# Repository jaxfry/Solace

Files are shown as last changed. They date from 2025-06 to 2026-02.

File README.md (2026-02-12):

<div align="center">

# Solace

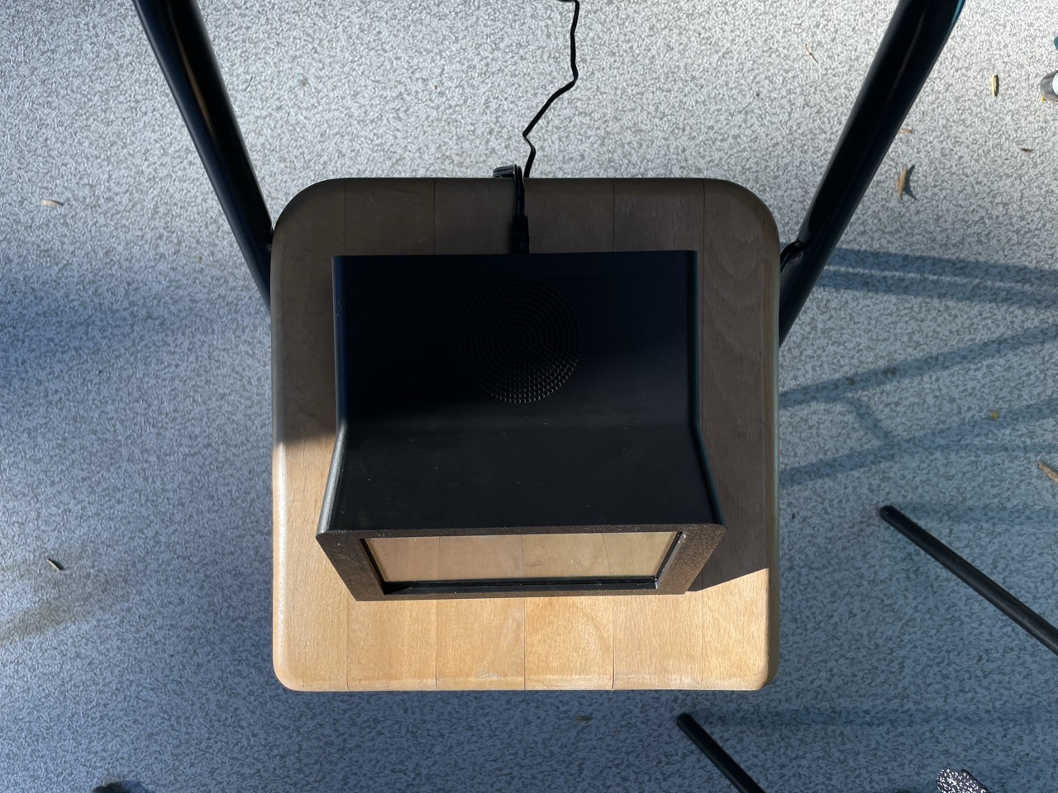
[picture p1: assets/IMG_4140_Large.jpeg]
Solace Build


## Description

**What is Solace?**

Solace is a physical extension of [LifeLog](https://github.com/jaxfry/LifeLog) that collects real-world data, displays real-time insights and statistics, and includes a voice assistant that integrates with the LifeLog system.

---

## Why I Made This

I wanted to create a physical device to complement the LifeLog system, providing a way to display data right beside my bed. I also wanted to create a voice assistant to further interact and for voice journal logging, a valuable data source.

---

## Project Pictures

### 3D Model

3D Model

### Wiring Diagram

Wiring Diagram

Please note that I used a generic buck converter in the diagram, but in the actual device I use a specific one.

### Bill of Materials (BOM)
|Part Name |Quantity|Price (CAD)|Description |Link |
|---|---|---|---|---|
|PLS-P830985 |1 |$30.65 |Speaker |https://www.digikey.ca/en/products/detail/peerless-by-tymphany/PLS-P830985/6211132 |
|Raspberry Pi Touch Display V1 |1 |$85.95 |7-inch touchscreen display for Raspberry Pi |https://www.digikey.ca/en/products/detail/raspberry-pi/ASIN-B00X4WHP5E/6211133 |
|Raspberry Pi 4 2GB |1 |$80.16 |Mini computer |https://www.amazon.ca/Raspberry-Model-2019-Quad-Bluetooth/dp/B07TD42S27/ |
|DAOKAI TPA3118 Mono Amplifier Board |1 |$9.14 |Audio amplifier for Raspberry Pi |https://www.amazon.ca/gp/product/B07SGK3VFS/ |
|TR9CE5000CCP-N(R6B) |1 |$$30.66 |power supply |https://www.digikey.ca/en/products/detail/mean-well-usa-inc/GST60A12-P1J/7703712 |
|PJ-037AH |1 |$1.01 |Power Jack |https://www.digikey.ca/en/products/detail/same-sky-formerly-cui-devices/PJ-037AH/1644547 |
|USB Mini Mic |1 |$6.99 |USB microphone for audio input |https://www.amazon.ca/Mini-Microphone-Skype-Desktop-Laptop/dp/B076BC2Y3W/ |
|0297005.U |1 |$0.57 |A 5A fuse, so I don't burn my house down |https://www.digikey.ca/en/products/detail/littelfuse-inc/0297005-U/3427486 |
|OKR-T/6-W12-C |1 |$13.89 |Buck converter |https://www.digikey.ca/en/products/detail/murata-power-solutions-inc/OKR-T-6-W12-C/2199629 |
|Aux Cable 1Ft |1 |$6.99 |A 1ft aux cable to connect the amp to the Raspberry Pi |https://www.amazon.ca/Tan-QY-Auxiliary-Compatible-Headphones/dp/B08BNMJ3ND/ |
|3021451F5701(R) |1 |$7.11 |Power Cord |https://www.digikey.ca/en/products/detail/globtek-inc/3021451F5701-R/8597816 |
|MFR-25FRF52-2K7 |1 |$0.15 |RES 2.7K OHM 1% 1/4W AXIAL |https://www.digikey.ca/en/products/detail/yageo/MFR-25FRF52-2K7/9138955 |
|EEU-FC1E101S |1 |$0.55 |Capacitor 100uF 25V |https://www.digikey.ca/en/products/detail/panasonic-electronic-components/EEU-FC1E101S/266278 |
|EEU-FR1A101 |1 |$0.47 |Capacitor 100uF 10V |https://www.digikey.ca/en/products/detail/panasonic-electronic-components/EEU-FR1A101/2433507 |
|C315C104M5U5TA |2 |$0.41 |Capacitor 0.1uF 50V |https://www.digikey.ca/en/products/detail/kemet/C315C104M5U5TA/817927 |
|28A2025-0A2 |1 |$3.84 |FERRITE CORE 320 OHM HINGED |https://www.digikey.ca/en/products/detail/laird-signal-integrity-products/28A2025-0A2/242803 |
|2Pack USB 3.0 Male to Female Adapter 7.9inches (20cm)|1 |$7.90 |USB 3.0 extension cable |https://www.amazon.ca/Female-Extension-Cable-Male-Female/dp/B084WPG7QG/ |
|110991327 |1 |$1.54 |Heat sink for the Raspberry Pi 4 |https://www.digikey.ca/en/products/detail/seeed-technology-co-ltd/110991327/10451876 |
|0FHM0001ZXJ |1 |$12.74 |Fuse Holder |https://www.digikey.ca/en/products/detail/littelfuse-commercial-vehicle-products/0FHM0001ZXJ/2004060|
|M2.5 Standoff kit |1 |$9.67 |M2.5 Standoff kit for mounting the Raspberry Pi and other components|https://www.amazon.ca/XLX-Male-Female-Female-Female-Assortment-Stainless/dp/B07FMV5RMG/ |
|FIT0585 |1 |$4.55 |18 AWG Wire |https://www.digikey.ca/en/products/detail/dfrobot/FIT0585/9559254?gQT=1 |
|uxcell |1 |$6.75 |M4*12 screws for speaker |https://www.amazon.ca/gp/product/B0F1YR73PB/ |
|Total | |$328.94 | | |

### Final Product Pictures
Final Product

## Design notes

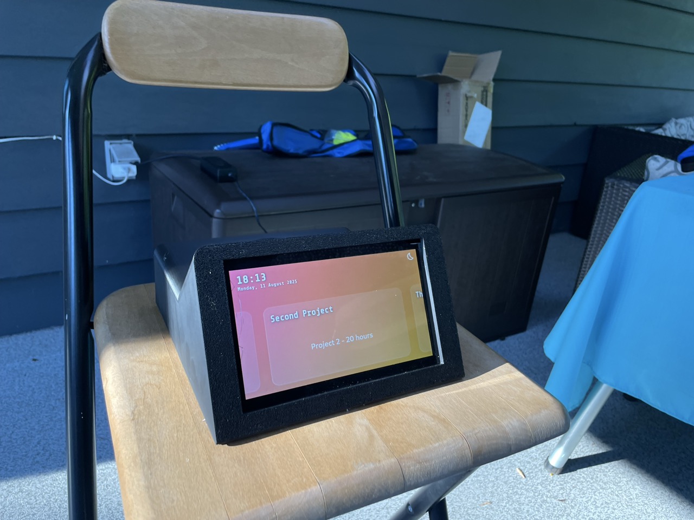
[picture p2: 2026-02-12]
assets/IMG_4137 Large.jpeg

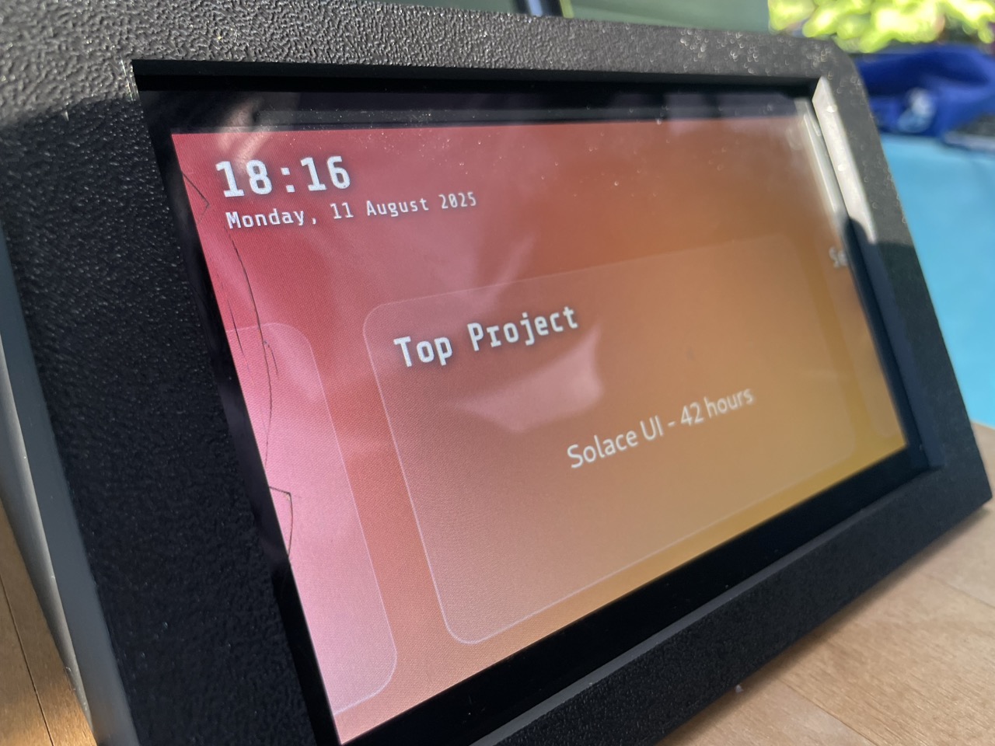
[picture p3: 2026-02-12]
assets/IMG_4144 Large.jpeg

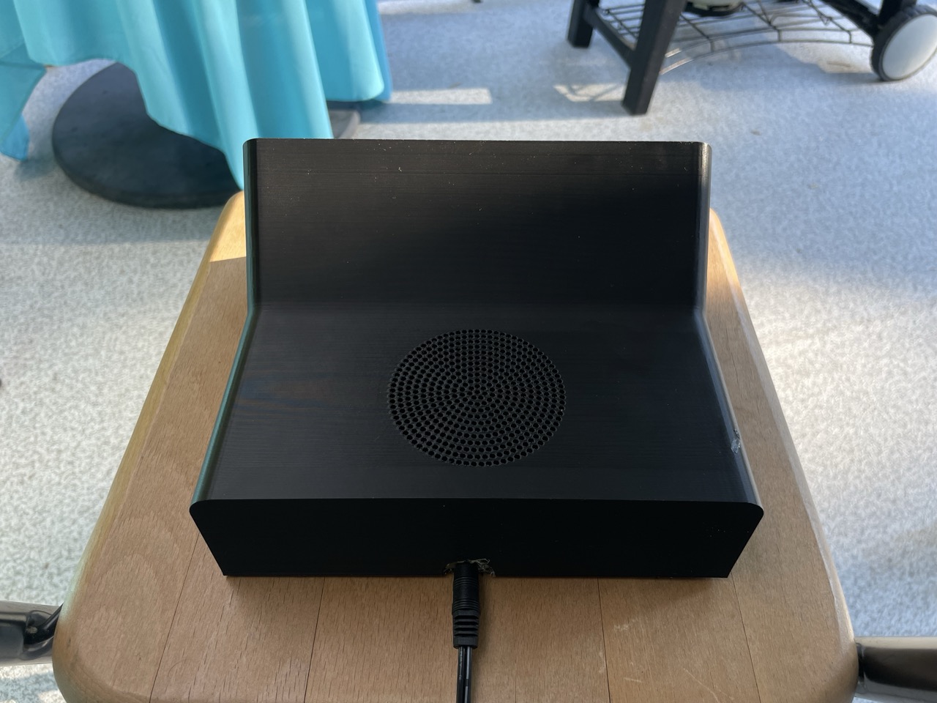
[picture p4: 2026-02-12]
assets/IMG_4146 Large.jpeg

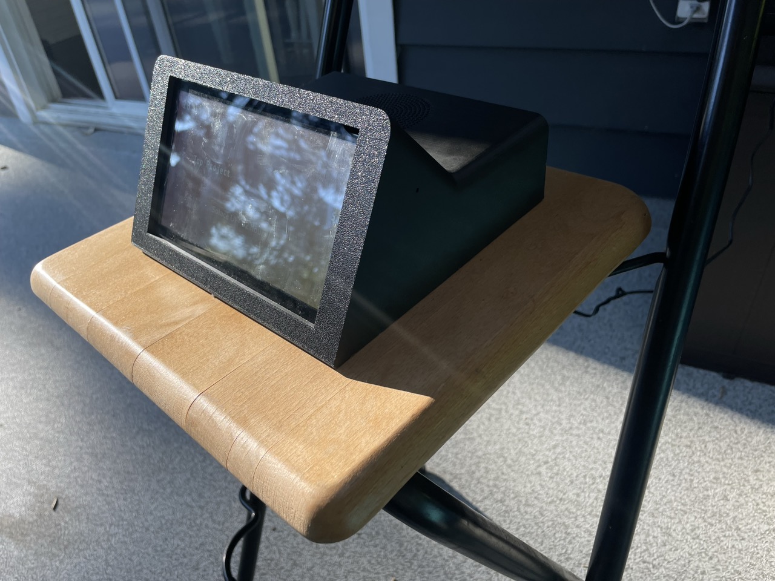
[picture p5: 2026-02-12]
assets/IMG_4142 Large.jpeg

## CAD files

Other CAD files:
Solace_CAD.f3d

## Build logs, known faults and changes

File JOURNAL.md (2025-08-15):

---
title: "Solace"
author: "Jaxon"
description: "A DIY Braun DN40-inspired alarm clock that’s also a LifeLog Satellite and smart speaker."
created_at: "2025-06-28"
total_design_time: "20 hours"
total_build_time: "~11 hours"
total_time: "~31 hours"
---
# 28 June 2025 - Project Kick-off (3 Hours)
- Drafted project goals and some technical details
- Flashed Raspberry Pi 3 for testing
- Sucsessfully got display to connect
- Got flutter set up and demo working
- Set up dev enviroment on macbook
- Started (re)Learning Flutter Basics
- Started thinking about the layout of the UI
# 29 June 2025 - Components Research (1 hour)
I was researching different types of displays, but ended up deciding upon a standard raspberry pi display after much concideration for a nice AMOLED screen, it's just too expensive. I'll make a BOM soon!
# 29 June 2025 - Design sketch (30 mins)
- Just sketched a design and wrote about Solace and LifeLog.
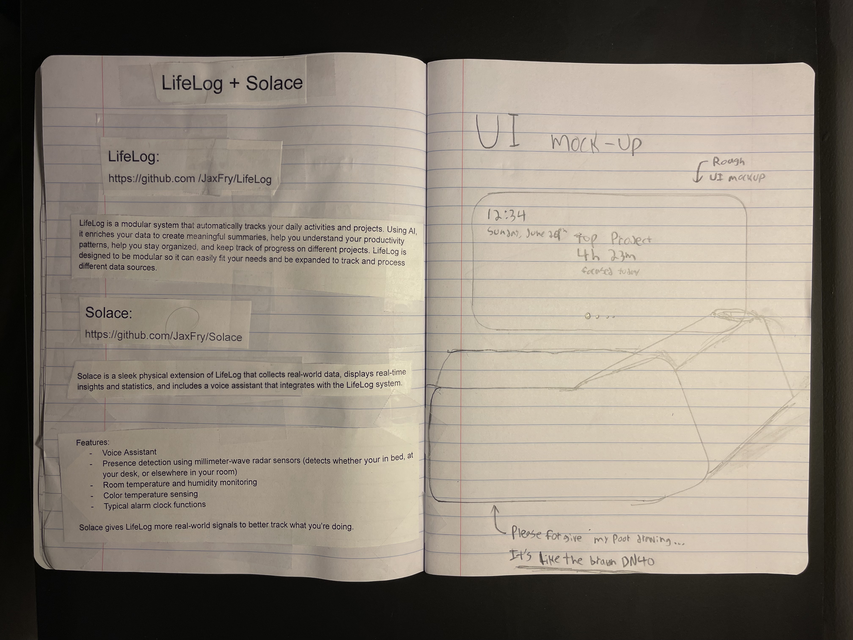
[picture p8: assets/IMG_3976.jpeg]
notebook

# 30 June 2025 - Design Prototype Case (3 hours)
Today I designed two iterations of the case all while rembering how to use Fusion 360, just a very early testing stage with some broken screen (honestly might be a safty hazard if it wasn't hidden by the case) and stuff I've got laying around. I plan to redesign it to fit what ever display I end up choosing. On that note, I've got almost all of the components picked out except the display... I know, I started concidering the OLED screens again.
Case Prototype
# 1 July 2025 - UI Implementation (1 hour)
- Today I was limited on time, but I tested different fonts, spacing, and colors. I also added some nice color gradents depending on what time of day it is. Tomorrow I plan to add pages to the UI, and hook it into the LifeLog API!
UI
# 1 July into 2 July - Picking Parts, CAD, and Research (past mid-might, 4 hours)
I stayed up until at least 1am doing this. I'm tired.
- I realized I knew very little about the audio world, but through research I figured out that your enclosure size maters when picking a speaker. As a result of this I had to ensure that it would still sound good in my case. I've decided on the PLS-P830985 as it's budget friendly and small enough to fit inside my project. I found a better alternitive, but it was $100, out of my budget.
- On the cad design, I fixed some minor issues like some misalignments.
- Made progress on the BOM!
# 2 July - Finalizing BOM and Research (3.5 hours)
Today we went to a water park, so I had tons of time in the car and when I got home to work on the project.
*(OUTDATED BOM, SEE README.md)*
|Part Name |Quantity|Price (CAD) |Description |Link |
|---|---|---|---|---|
|PLS-P830985 |1 |$30.65 |Speaker |https://www.digikey.ca/en/products/detail/peerless-by-tymphany/PLS-P830985/6211132 |
|Raspberry Pi Touch Display V1 |1 |$85.95 |7-inch touchscreen display for Raspberry Pi |https://www.digikey.ca/en/products/detail/raspberry-pi/ASIN-B00X4WHP5E/6211133 |
|Raspberry Pi 4 2GB |1 |$80.16 |Mini computer |https://www.amazon.ca/Raspberry-Model-2019-Quad-Bluetooth/dp/B07TD42S27/ |
|Stereo 20W Class D Audio Amplifier - MAX9744 |1 |$19.95 |Audio amplifier for Raspberry Pi |https://www.digikey.ca/en/products/detail/adafruit-industries-llc/1752/4990780 |
|GST60A12-P1J |1 |$27.10 |power supply |https://www.digikey.ca/en/products/detail/mean-well-usa-inc/GST60A12-P1J/7703712 |
|PJ-037AH |1 |$1.01 |Power Jack |https://www.digikey.ca/en/products/detail/same-sky-formerly-cui-devices/PJ-037AH/1644547 |
|USB Mini Mic |1 |$6.99 |USB microphone for audio input |https://www.amazon.ca/Mini-Microphone-Skype-Desktop-Laptop/dp/B076BC2Y3W/ |
|0297005.U |1 |$0.57 |A 5A fuse, so I don't burn my house down |https://www.digikey.ca/en/products/detail/littelfuse-inc/0297005-U/3427486 |
|OKR-T/6-W12-C |1 |$13.89 |Buck converter |https://www.digikey.ca/en/products/detail/murata-power-solutions-inc/OKR-T-6-W12-C/2199629 |
|Aux Cable 1Ft |1 |$6.99 |A 1ft aux cable to connect the amp to the Raspberry Pi |https://www.amazon.ca/Tan-QY-Auxiliary-Compatible-Headphones/dp/B08BNMJ3ND/ |
|4698 |1 |$23.24 |Color Light Sensor |https://www.digikey.ca/en/products/detail/adafruit-industries-llc/4698/13162109 |
|LSYGXYZ 6 Pieces Acrylic Rods |1 |$8.99 |Acrylic rods to have the light sensor inside the case |https://www.amazon.ca/LSYGXYZ-Acrylic-Decorations-Gardening%EF%BC%883mm-Diameter%EF%BC%89/dp/B09M846847/ |
|PC-ABK006F |1 |$7.11 |Power Cord |https://www.digikey.ca/en/products/detail/bel-inc/PC-ABK006F/15777826 |
|MFR-25FBF52-33K |1 |$0.15 |Resistor 33K Ohm 1/4W |https://www.digikey.ca/en/products/detail/yageo/MFR-25FBF52-33K/9138137 |
|EEU-FC1E101S |1 |$0.55 |Capacitor 100uF 25V |https://www.digikey.ca/en/products/detail/panasonic-electronic-components/EEU-FC1E101S/266278 |
|EEU-FR1A101 |1 |$0.47 |Capacitor 100uF 10V |https://www.digikey.ca/en/products/detail/panasonic-electronic-components/EEU-FR1A101/2433507 |
|C315C104M5U5TA |2 |$0.41 |Capacitor 0.1uF 50V |https://www.digikey.ca/en/products/detail/kemet/C315C104M5U5TA/817927 |
|28A2025-0A2 |1 |$3.84 |FERRITE CORE 320 OHM HINGED |https://www.digikey.ca/en/products/detail/laird-signal-integrity-products/28A2025-0A2/242803 |
|2Pack USB 3.0 Male to Female Adapter 7.9inches (20cm)|1 |$7.90 |USB 3.0 extension cable |https://www.amazon.ca/Female-Extension-Cable-Male-Female/dp/B084WPG7QG/ |
|110991327 |1 |$1.54 |Heat sink for the Raspberry Pi 4 |https://www.digikey.ca/en/products/detail/seeed-technology-co-ltd/110991327/10451876 |
|0FHM0001ZXJ |1 |$12.74 |Fuse Holder |https://www.digikey.ca/en/products/detail/littelfuse-commercial-vehicle-products/0FHM0001ZXJ/2004060 |
|M2.5 Standoff kit |1 |$9.67 |M2.5 Standoff kit for mounting the Raspberry Pi and other components |https://www.amazon.ca/XLX-Male-Female-Female-Female-Assortment-Stainless/dp/B07FMV5RMG/ |
|M3 x 10mm |1 |$12.86 |M3 x 10mm Thread Pitch screws for mounting the Raspberry Pi and other components |https://www.amazon.ca/iexcell-Thread-Socket-Button-Screws/dp/B0CP4BLD7Z/ |
|FIT0585 |1 |$4.55 |18 AWG Wire |https://www.digikey.ca/en/products/detail/dfrobot/FIT0585/9559254?gQT=1 |
|MMOBIEL 20 Gauge Electrical Wire Parallel - 20 AWG |1 |$11.49 |20 AWG Wire |https://www.amazon.ca/MMOBIEL-Gauge-Electrical-Wire-Parallel/dp/B0DGV5V2SM |
|4397 |1 |$1.38 |STEMMA/Qwiic cable |https://www.digikey.ca/en/products/detail/adafruit-industries-llc/4397/10824270 |

Everything is crazy expensive :sob:, good thing I already have the display and pi!
# 3 July - Completed BOM (1 hour)
I completed the BOM, and now I'm going to finalize the case design and finish the code.
# 5 July - Case Design, Parts Update, and Code (3.5 hours)
- I added the speaker to the case design
- updated the BOM to remove a few unnecessary parts.
- I wrote a simple voice assistant that hooks into the Gemini API.
- Updated wiring diagram
3D Model Update
# 11 August - Start and almost finish assembling (4 hours)
- I soldered everything! Not much more to say then that.
- I thought it wasn't working, but I forgot I made it so that past 10pm it would dim the display a lot and the viewing angle is terrible so I couldn't see it. :skull:
- Need to modify the voice assistant code.
# 12 August - Solder everything 100% (2 hours)
- I soldered the speaker, the power jack, pi, dc-dc converter, JUST everything!
# 13 August - Final Assembly and rewrite of the entire code! (5 hours)
- I finished the code for the voice assistant, and it works!
- YAY!
- Check readme for the final pictures :) I think it turned out great!

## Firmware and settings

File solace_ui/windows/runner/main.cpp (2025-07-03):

#include <flutter/dart_project.h>
#include <flutter/flutter_view_controller.h>
#include <windows.h>

#include "flutter_window.h"
#include "utils.h"

int APIENTRY wWinMain(_In_ HINSTANCE instance, _In_opt_ HINSTANCE prev,
                      _In_ wchar_t *command_line, _In_ int show_command) {
  // Attach to console when present (e.g., 'flutter run') or create a
  // new console when running with a debugger.
  if (!::AttachConsole(ATTACH_PARENT_PROCESS) && ::IsDebuggerPresent()) {
    CreateAndAttachConsole();
  }

  // Initialize COM, so that it is available for use in the library and/or
  // plugins.
  ::CoInitializeEx(nullptr, COINIT_APARTMENTTHREADED);

  flutter::DartProject project(L"data");

  std::vector<std::string> command_line_arguments =
      GetCommandLineArguments();

  project.set_dart_entrypoint_arguments(std::move(command_line_arguments));

  FlutterWindow window(project);
  Win32Window::Point origin(10, 10);
  Win32Window::Size size(1280, 720);
  if (!window.Create(L"Solace UI", origin, size)) {
    return EXIT_FAILURE;
  }
  window.SetQuitOnClose(true);

  ::MSG msg;
  while (::GetMessage(&msg, nullptr, 0, 0)) {
    ::TranslateMessage(&msg);
    ::DispatchMessage(&msg);
  }

  ::CoUninitialize();
  return EXIT_SUCCESS;
}

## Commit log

2025-07-03 Added BOM
    [BOM.CSV]
2025-07-03 Update BOM
    [BOM.CSV]
2025-07-03 remove expensive stuff
    [BOM.CSV]
2025-07-03 update readme and such
    [BOM.CSV]
2025-07-06 large update
    [BOM.CSV]
2025-07-06 Fix weird comit
    [Solace_CAD.f3d]
2025-07-06 update wiring diagram
2025-07-08 update cad
    [Solace_CAD.f3d]
2025-07-18 Update silly mistakes
    [BOM.CSV]
2025-07-22 fix more silly mistakes
    [BOM.CSV]
